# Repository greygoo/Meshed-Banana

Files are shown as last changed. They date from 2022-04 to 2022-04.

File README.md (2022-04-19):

# THIS IS WORK IN PROGRESS, PLEASE IGNORE UNTIL THIS MESSAGE IS REMOVED *

# Meshed Banana

</p>
<p align="center" width="60%">
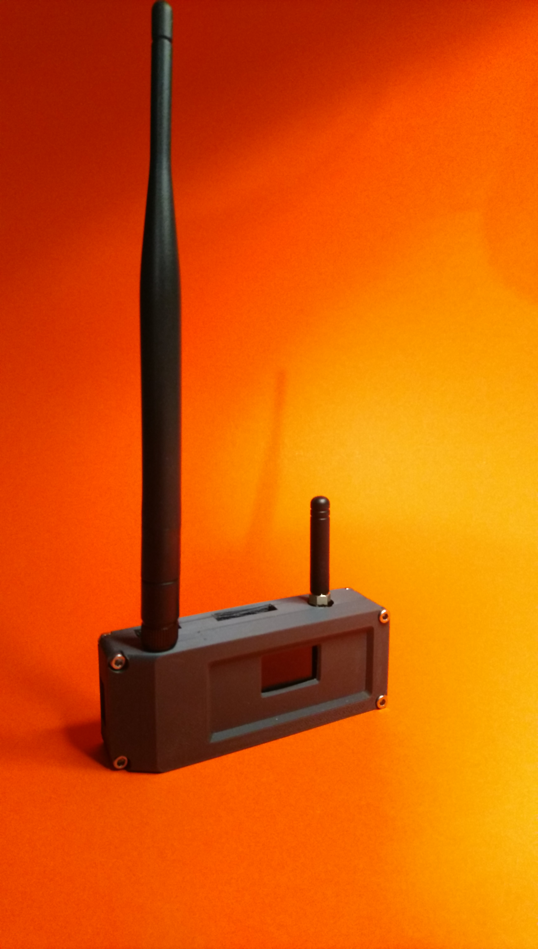
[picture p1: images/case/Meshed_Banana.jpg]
  
</p>

## What is it?
Meshed Banana is LoRa Router for the Reticulum Mesh protocol. It consists of a ESP32 LoRa device connected to a Banana Pi Zero M2 running the reticulum mesh network stack.

_Why a Banana Pi Zero?_
_Simply due to the sparsity of the Raspberry Pi Zero, the Banana Pi version was chosen as it has the same size and thus can be exchanged, giving you the option of a Meshed Raspberry. All build instructions given here can also be applied to a raspberry pi zero, only the Banana Pi Zero disk image will not work on a Raspberry Pi, a working image will be provided in the future._
 
## What can it do?
Other than mesh networking projects like e.g. meshtastic, the reticulum stack is not restricted to a LoRa network, but can also be used over other rf based networks like cb radio as well as internet protocols like TCP/IP or I2P. This enables users to bridge LoRa networks into the internet and thus giving the ability to connect separated rf based networks or extend connectivity via rf.

The "downside" of the reticulum stack is that it is not running on the microprocessor itself, but is written in python and thus requires some python capable system - here the banana pi zero (it is not yet micropython capable, the main missing part is the python cryptography module).

## What can't it do?
Reticulum, despite its stability, is still in an early stage. Therefor a number of features have not yet been implemented. Also, it is an own protocol, requiring applications to make use of it. Currently there are only a number of examples and a chat application that can be used for testing. However - creating your own applications in Python is not very difficult and an introduction can be found here: <link to reticulum own apps>. So here a short overview of what works and what does not work yet:

Works:
- Mesh network functionality over TCP/IP, I2P, KISS, LoRa
- SMS like direct 1on1 chat using a terminal application or an Android phone
- Serving and accessing pages written in a markdown like language
- Dending and receiving files
- Using the reticulum capable [Sideband Android App](https://unsigned.io/sideband/)

Does not work (yet)
- group chat
- a lot I can't think of right now ;)

For more details on reticulum features and a roadmap, please check out the [documentation on reticulum](https://markqvist.github.io/Reticulum/manual/)  
  
## How does it work?
The principle of Meshed Banana is to connect on one side to other LoRa nodes in range and on the other side to a local Wifi network. It then runs a reticulum mesh node which is accessible from Wifi and LoRa and forwards reticulum packages from one network to the other.
This gives some possible use cases:
- Run sensors in a LoRa network, and access the data via your WiFi network on e.g. a mobile phone that runs a reticulum enabled app
- Put a Meshed Banana in your home and in your neighbors home and enjoy your fully private encrypted mesh network
- Connect a cb radio via an TNC to two Meshed Bananas and connect two isolated sites over large distances
- ...

## What does it include?
Meshed Banana tries to make it as easy as possible to use reticulum, therefor it consists of:
- stl files for a case<link>
- instructions on how to connect everything<link>
- a banana pi zero m2 armbian image including all required software<link>

## Why don't you just connect a ESP32 Lora device to your Laptop?
That would be too easy ;)
The main reason for this project was to create a device that can be given to unexperienced user to enable him to take part in a LoRa Mesh network withou much for him to setup.

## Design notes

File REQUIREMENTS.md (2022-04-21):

# Required Hardware

## Banana Pi Zero

**Name** Banana Pi M2 Zero<br>
**URL** https://wiki.banana-pi.org/Banana_Pi_BPI-M2_ZERO<br>
**Source** https://www.reichelt.de/banana-pi-m2-zero-1-2-ghz-quad-core-512-mb-ddr3-banana-pi-zero-p218297.html<br>

<p align="left" width="60%">
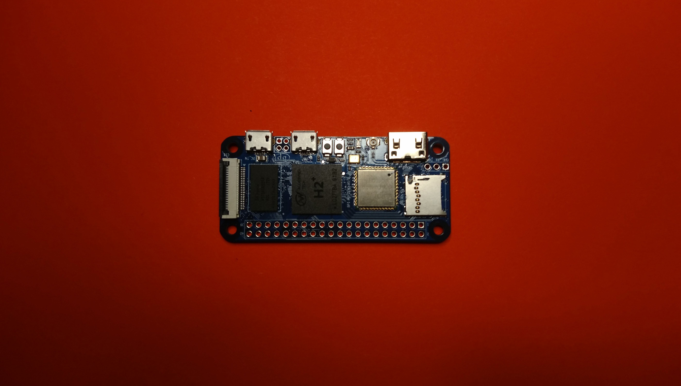
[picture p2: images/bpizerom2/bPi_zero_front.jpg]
  
</p>

## ESP32 based LoRa module

**Name** LILYGO® TTGO ESP32-Paxcounter LoRa32 V2.1 1.6<br>
**URL** http://www.lilygo.cn/prod_view.aspx?TypeId=50003&Id=1130&FId=t3:50003:3<br>
**Source** https://www.ebay.de/itm/164396959192<br>
**Frequency** 868 Mhz<br>

<p align="center" width="60%">
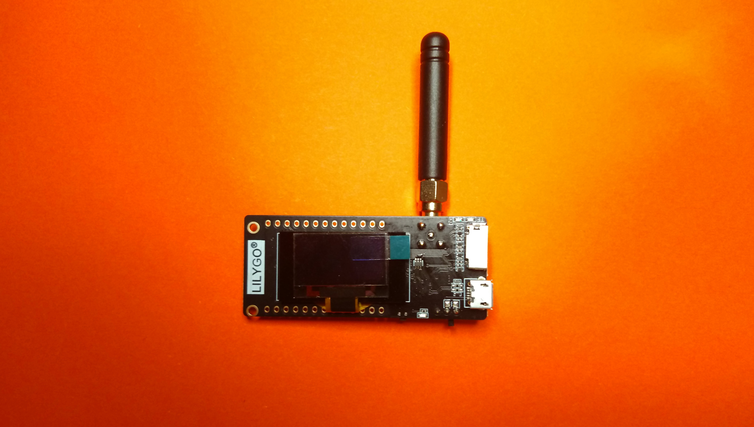
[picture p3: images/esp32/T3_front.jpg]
  
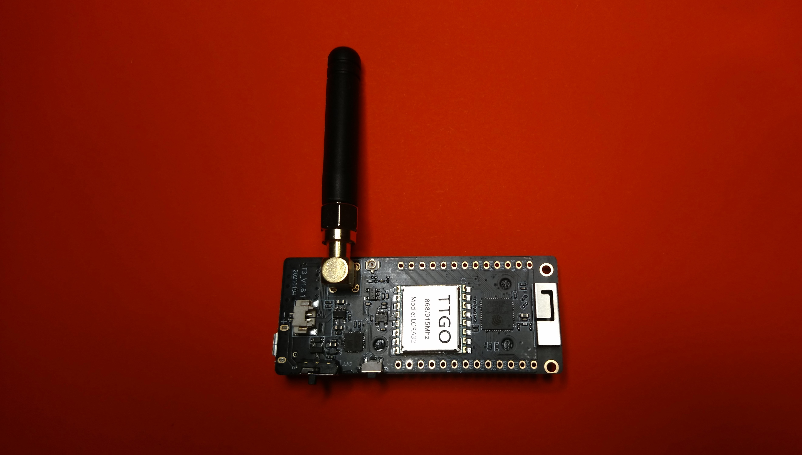
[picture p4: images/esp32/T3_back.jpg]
  
</p>

## WIFI Antenna

**Name** 2.4GHz WIFI antenna SMA Female<br>
**Source** https://www.ebay.de/itm/183989745716<br>

## SMA - IPEX adapter cable

**Name** RP-SMA(Male) to IPEX/U.FL Pigtail Cable<br>
**Source** https://www.ebay.de/itm/265495161098<br>

## Wires

Each approx. 30cm:
- red
- black
- green
- blue

## Connectors

1x Dupont connector female (6 pin)<br>
1x JST SM connector female (4 pin)<br>
1x JST SM connector male (4 pin)

## Screws

2x M2 x 5mm
4x M2.5 x 5mm
2x M3 x 18mm
2x M3 x 25mm

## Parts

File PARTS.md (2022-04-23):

# Required Hardware

## Banana Pi Zero

**Name** Banana Pi M2 Zero<br>
**URL** https://wiki.banana-pi.org/Banana_Pi_BPI-M2_ZERO<br>
**Source** https://www.reichelt.de/banana-pi-m2-zero-1-2-ghz-quad-core-512-mb-ddr3-banana-pi-zero-p218297.html<br>

<p align="left" width="60%">
  
</p>

## ESP32 based LoRa module

**Name** LILYGO® TTGO ESP32-Paxcounter LoRa32 V2.1 1.6<br>
**URL** http://www.lilygo.cn/prod_view.aspx?TypeId=50003&Id=1130&FId=t3:50003:3<br>
**Source** https://www.ebay.de/itm/164396959192<br>
**Frequency** 868 Mhz<br>

<p align="left" width="60%">
  
  
</p>

## WIFI Antenna

**Name** 2.4GHz WIFI antenna SMA Female<br>
**Source** https://www.ebay.de/itm/183989745716<br>

<p align="left" width="60%">
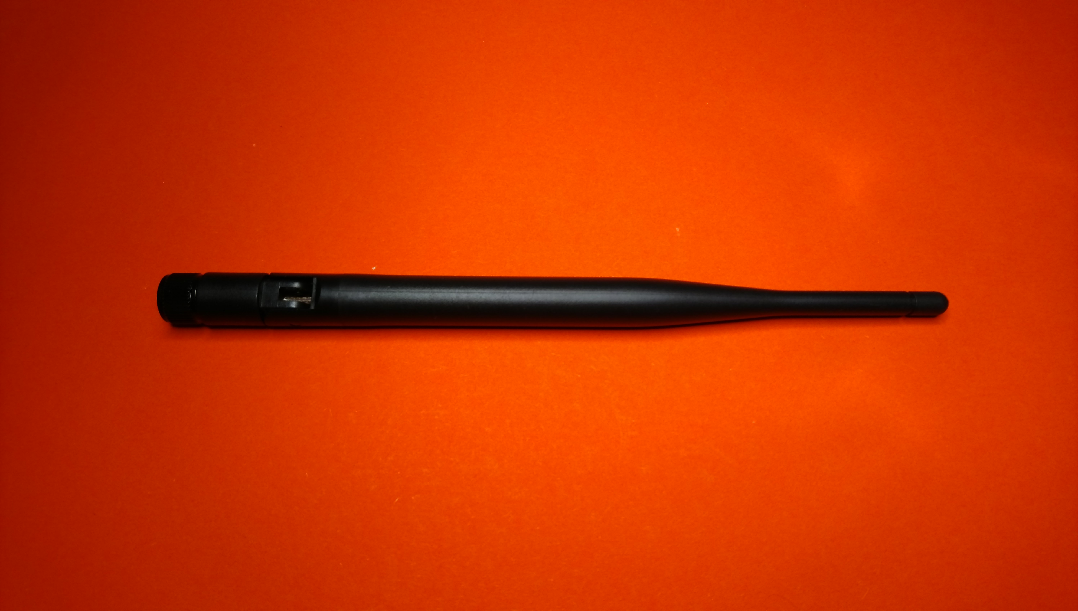
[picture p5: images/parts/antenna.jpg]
  
</p>

## SMA - IPEX adapter cable

**Name** RP-SMA(Male) to IPEX/U.FL Pigtail Cable<br>
**Source** https://www.ebay.de/itm/265495161098<br>

<p align="left" width="60%">
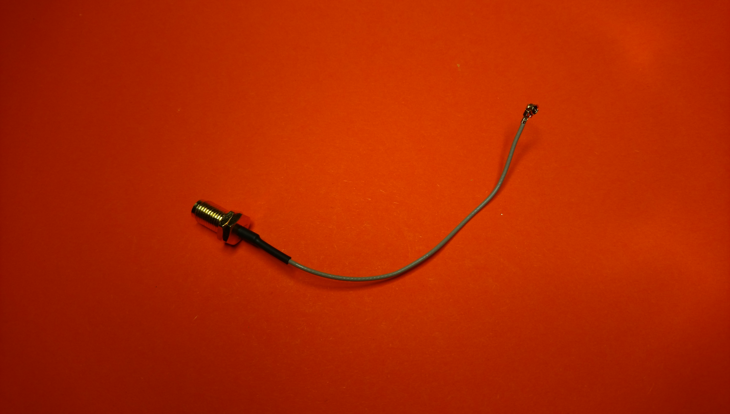
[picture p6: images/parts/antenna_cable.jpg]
  
</p>

## Connectors

1x Dupont connector female (6 pin)<br>

<p align="left" width="60%">
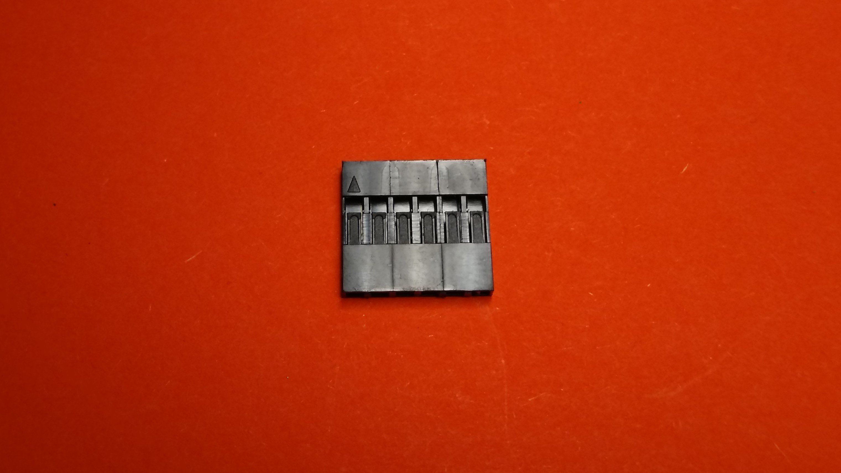
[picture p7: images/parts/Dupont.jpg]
  
</p>

1x JST SM connector female (4 pin)<br>
1x JST SM connector male (4 pin)
<p align="left" width="60%">
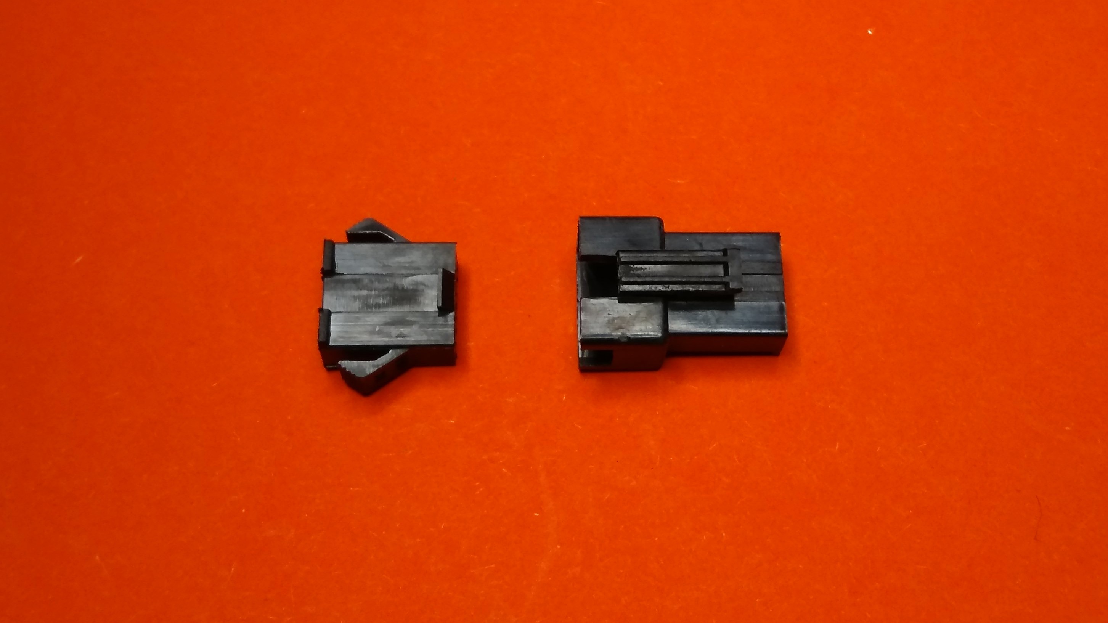
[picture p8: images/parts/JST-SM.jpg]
  
</p>

## Screws

2 x M2 x 5mm<br>
4 x M2.5 x 5mm<br>
2 x M3 x 18mm<br>
2 x M3 x 25mm

## Wires

Approx. 10cm:<br>
1 x Red<br>
1 x Black<br>
1 x Green<br>
1 x Blue<br>

Approx. 4cm:<br>
1 x Red<br>
2 x Black<br>
2 x Green<br>
2 x Blue<br>

Continue with [soldering in the wires](BUILD.md)

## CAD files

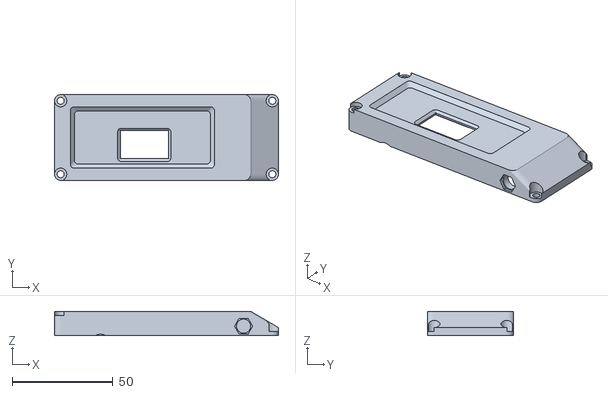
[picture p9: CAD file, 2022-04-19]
case/stl/Meshed_Banana_top.stl
111.0 x 42.5 x 12.0

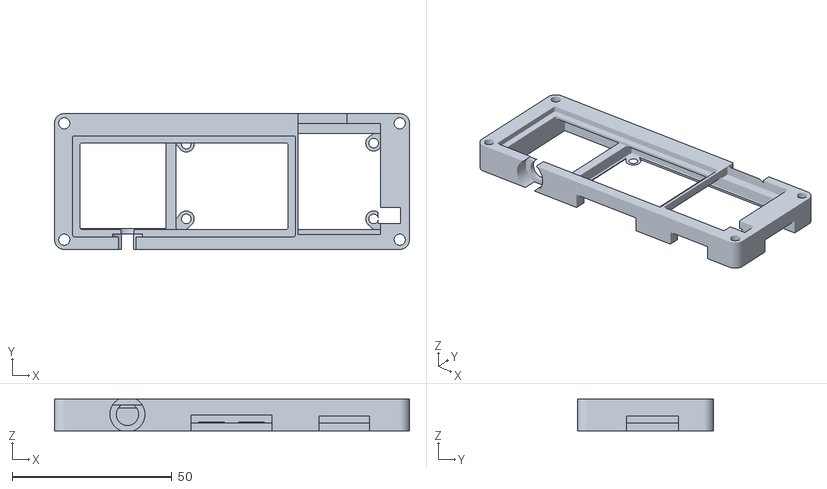
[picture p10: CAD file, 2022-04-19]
case/stl/Meshed_Banana_middle.stl
111.0 x 42.5 x 9.90

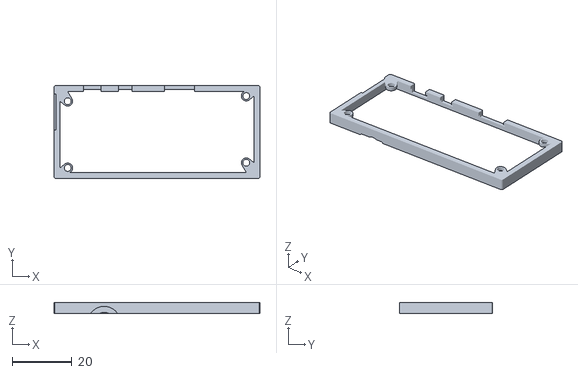
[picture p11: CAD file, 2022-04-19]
case/stl/Meshed_Banana_inlay_t3.stl
69.0 x 31.0 x 3.60

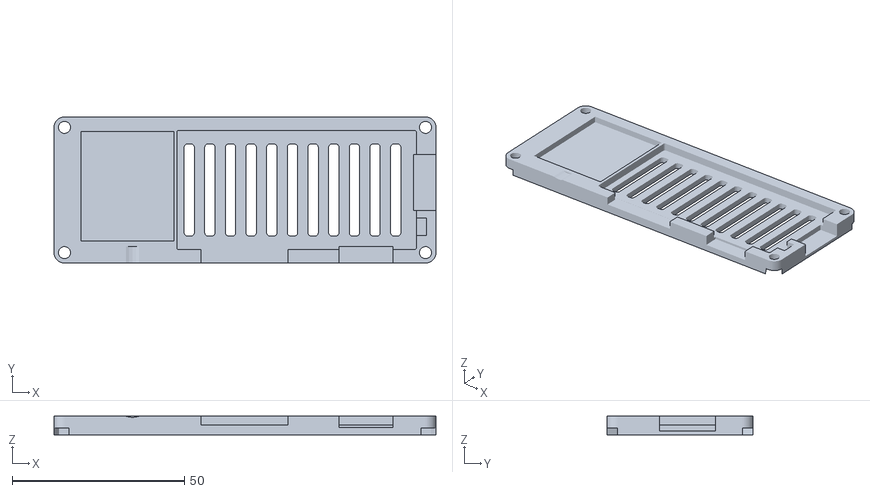
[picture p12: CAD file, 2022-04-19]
case/stl/Meshed_Banana_bottom.stl
111.0 x 42.5 x 5.40

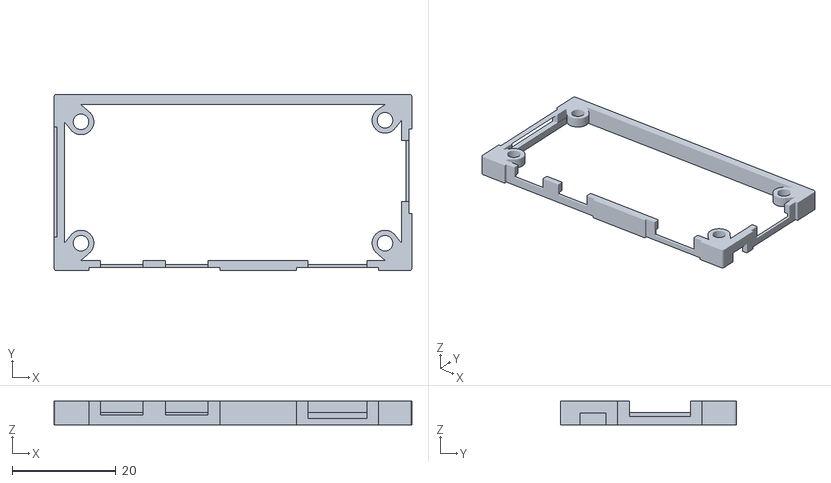
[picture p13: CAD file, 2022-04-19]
case/stl/Meshed_Banana_inlay_pi.stl
69.0 x 34.0 x 4.60

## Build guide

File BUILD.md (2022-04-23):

# Build

**Notes**

- TXD/RXD lines have to be crossed for a serial connection. This is achieved by switching the blue and green wire when soldering it into TXD and RXD connection, as seen in the pictures below.
- The TTGO LORA32 board is powered through the 3.3V pins from the Banana Pi Zero M2
- If you plan to use an HDMI monitor instead of a FTDI<->USB adapter, you can skip installing the debug connections (Steps 1 and 5)
- Your FTDI<->USB Adapter might have a different pinout, please make sure you put the pins into the Dupont connector accordingly (RXD/TXD lines crossed!).

1. Solder the 3 cables for the debug connection and 4 cables for the connection with the LORA3 to the Banana Pi Zero M2 

<p align="left" width="60%">
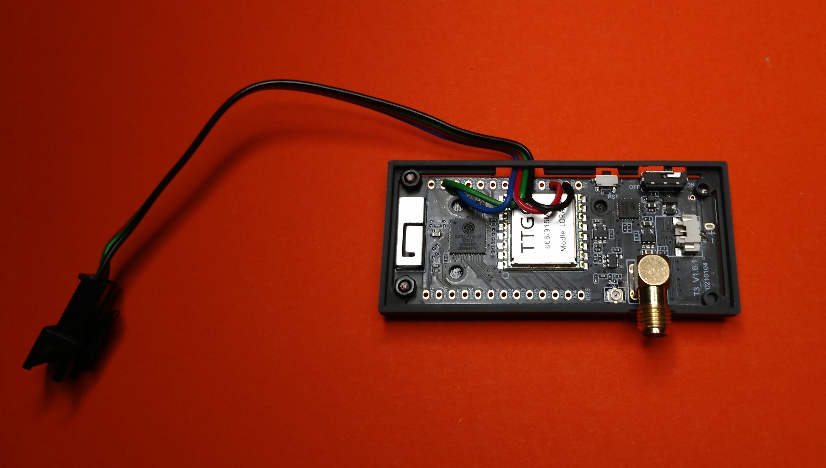
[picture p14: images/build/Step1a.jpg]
  
  
</p>

2. Solder the 4 cables for the connection with the LORA3 to the Banana Pi Zero M2 

<p align="left" width="60%">
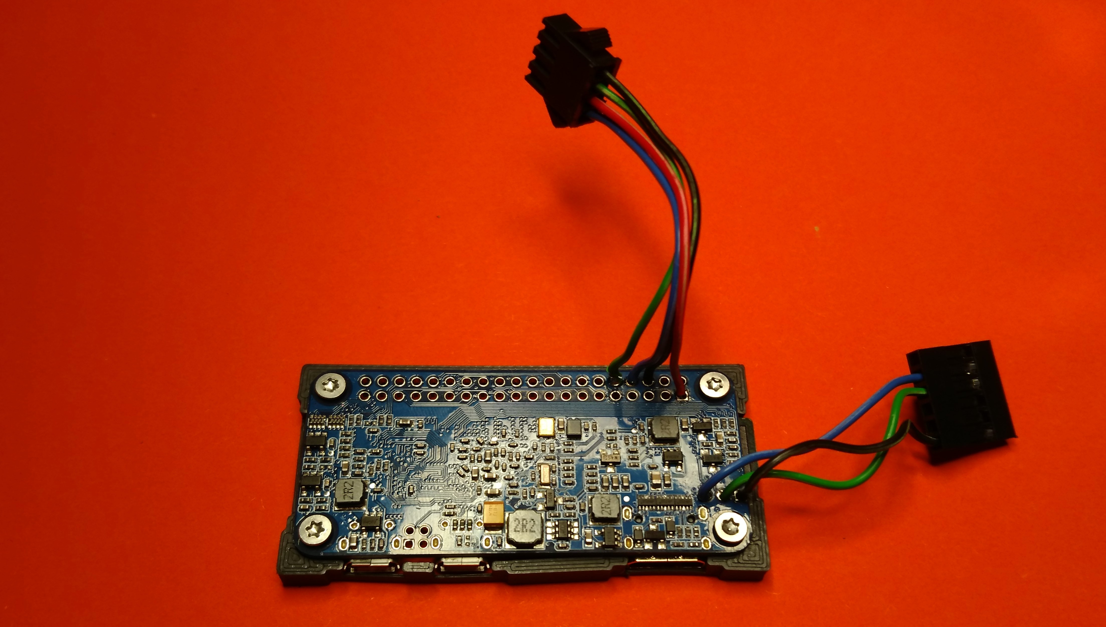
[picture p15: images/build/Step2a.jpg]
  
  
</p>

3. Solder the 4 cables for the connection with the Banana Pi Zero M2 to the TTGO LORA32

<p align="left" width="60%">
  
  
</p>

4. Join the JST-SM connectors with the 4 cables connecting Banana Pi Zero and TTGO LORA32

<p align="left" width="60%">
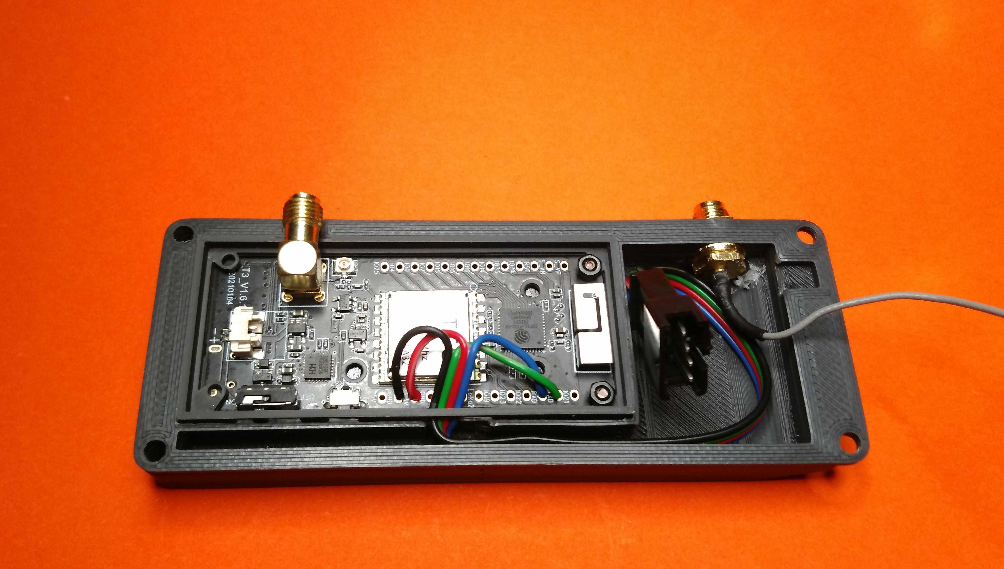
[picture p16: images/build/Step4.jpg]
  
</p>

5. Join the Dupont connector with the three debug cables from the Banana Pi Zero M2

<p align="left" width="60%">
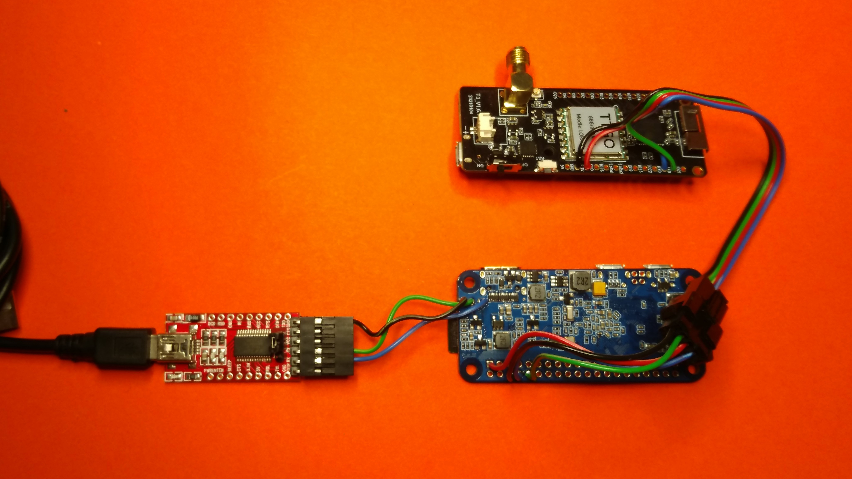
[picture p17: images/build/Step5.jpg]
  
</p>

6. Banana Pi Zero M2, TTGO LORA32 and a FTDI<->USB adapter connected

<p align="left" width="60%">
  
</p>

Continue with the [Assembly of the case](ASSEMBLY.md)

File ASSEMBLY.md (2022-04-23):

# Assembly

1. Screw the LoRa32 module in its frame using 2mm screws.
</p>
<p align="left" width="60%">
  
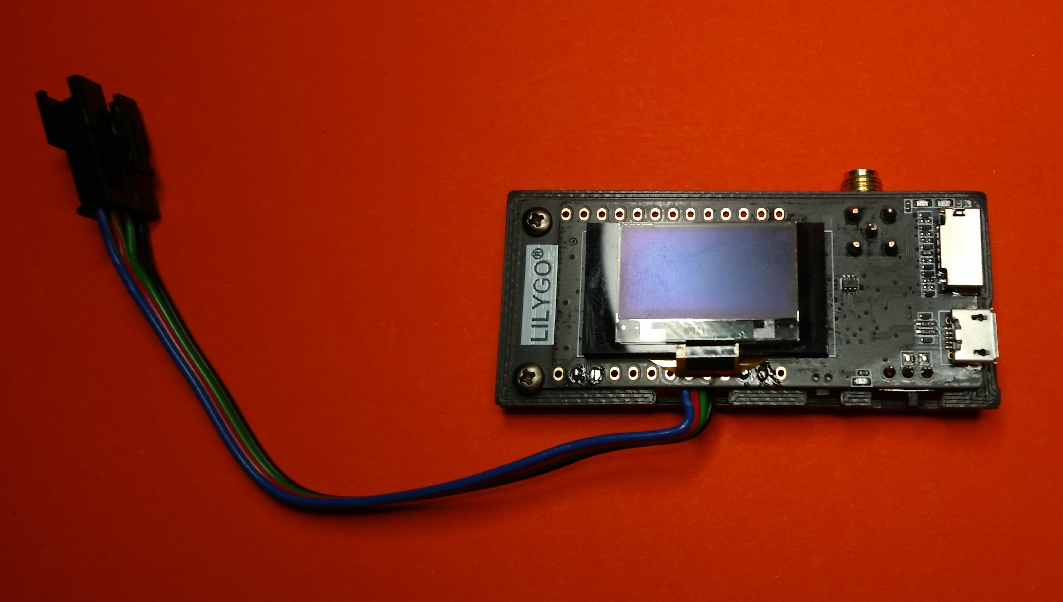
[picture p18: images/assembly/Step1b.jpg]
  
</p>

2. Screw the Banana Pi Zero into its frame using 2.5mm screws.
</p>
<p align="left" width="60%">
  
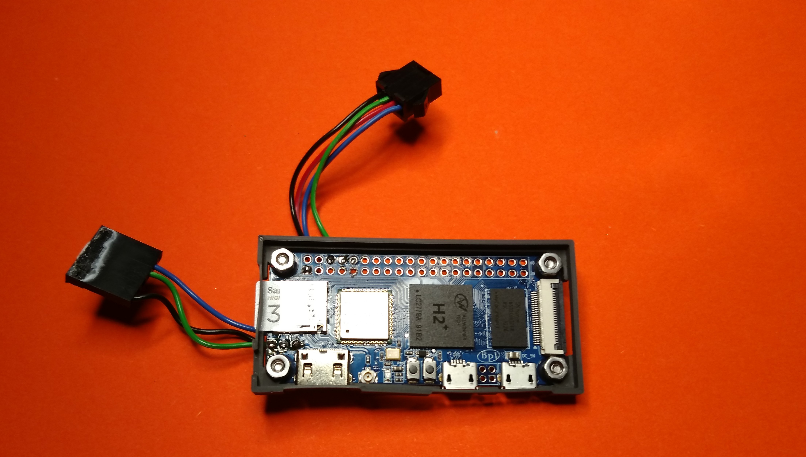
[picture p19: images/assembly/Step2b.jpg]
  
</p>

3. Screw the Antenna Cable into the top part of the case.
</p>
<p align="left" width="60%">
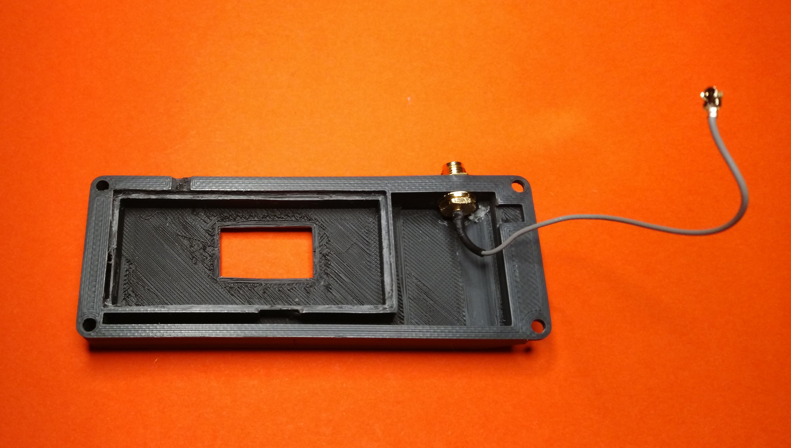
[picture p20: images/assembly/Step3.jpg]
  
</p>

4. Put the LoRa32 into the top case, make sure to run the cables as shown in the picture.
</p>
<p align="left" width="60%">
  
</p>

5. Add the middle part of the case.
</p>
<p align="left" width="60%">
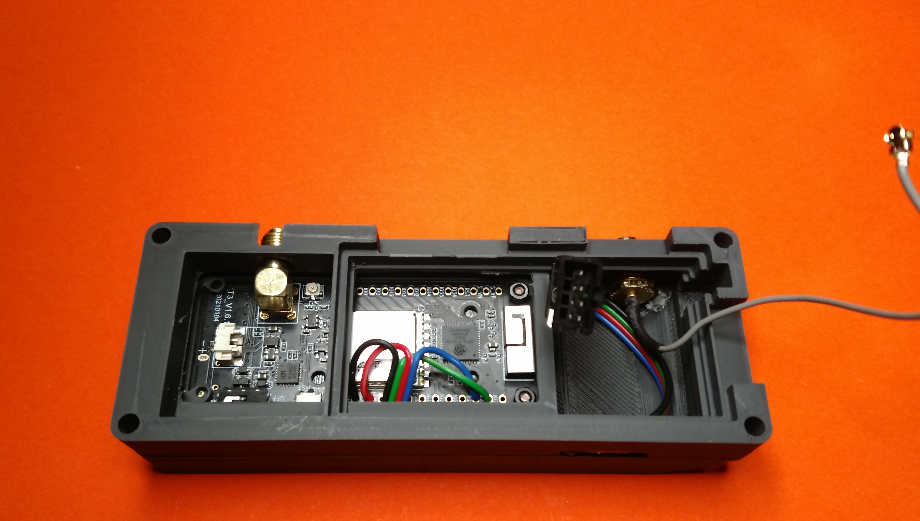
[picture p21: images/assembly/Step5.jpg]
  
</p>

6. Connect the Banana Pi Zero to the LoRa32 module and place the JST-SM connector in the case as shown in the picture.
</p>
<p align="left" width="60%">
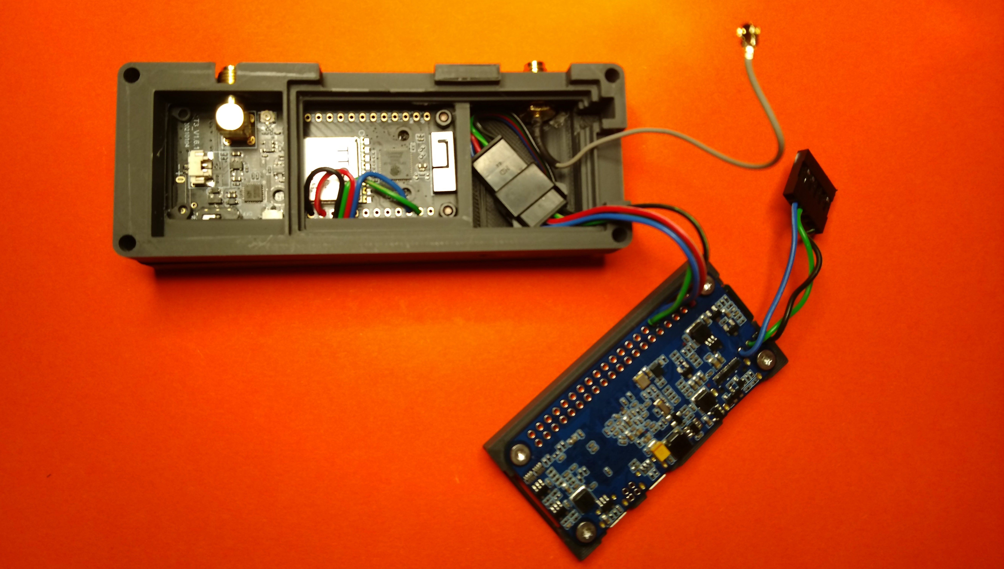
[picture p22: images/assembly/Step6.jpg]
  
</p>

7. Put the Dupont debug connector in the slot between top and middle case parts (It should be held in place once screws are tightened).
</p>
<p align="left" width="60%">
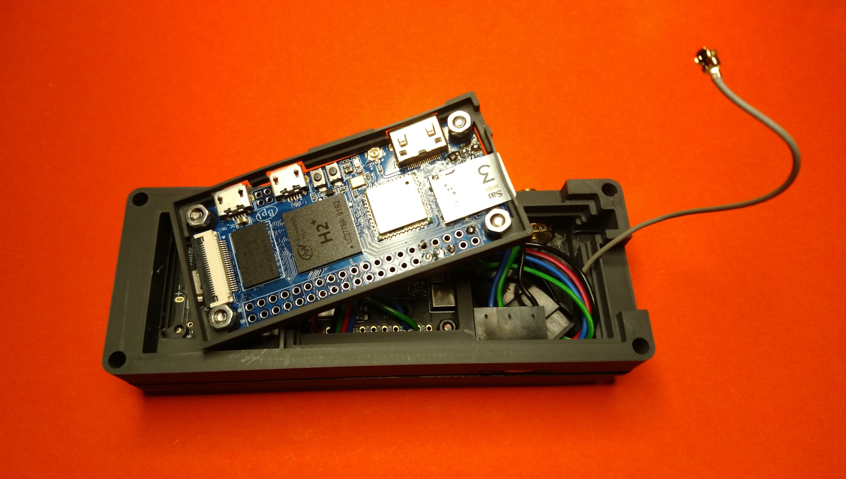
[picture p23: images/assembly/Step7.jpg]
  
</p>

8. Place the Banana Pi Zero in the middle case part. Lead the antenna cable through the gap and plug it into the Banana Pi Zero
</p>
<p align="left" width="60%">
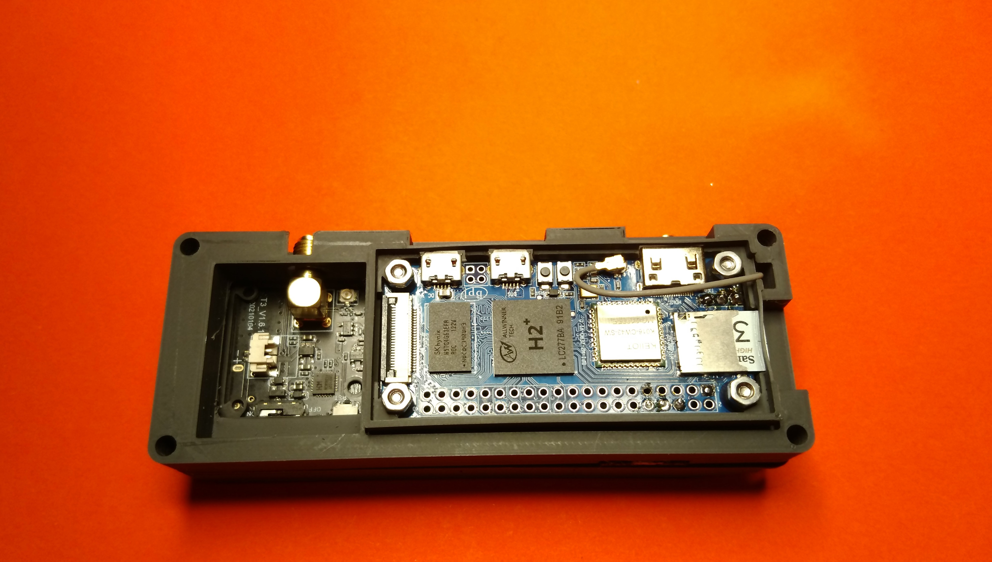
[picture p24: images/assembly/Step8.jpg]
  
</p>

9. Put the bottom case part on top and use 3mm screws to tighten it.
</p>
<p align="left" width="60%">
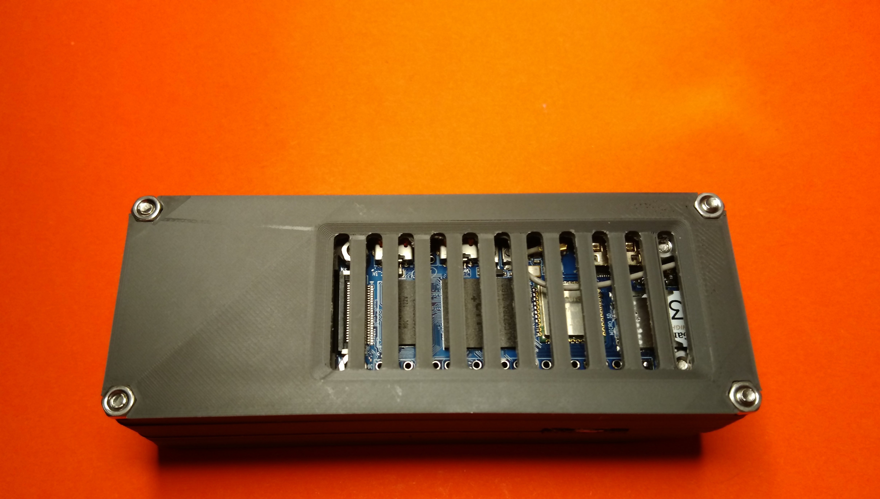
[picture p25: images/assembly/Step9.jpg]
  
</p>

10. Attach the antennas.
</p>
<p align="left" width="60%">
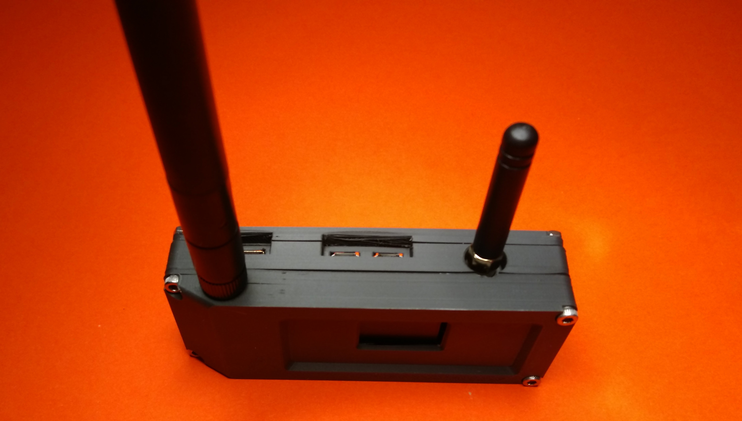
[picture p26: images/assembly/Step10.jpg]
  
</p>

11. One of:
  - Attach an serial<->USB adapter to the debug port and connect it via USB with your PC.
  - Connect a monitor via the HDMI port.
</p>
<p align="left" width="60%">
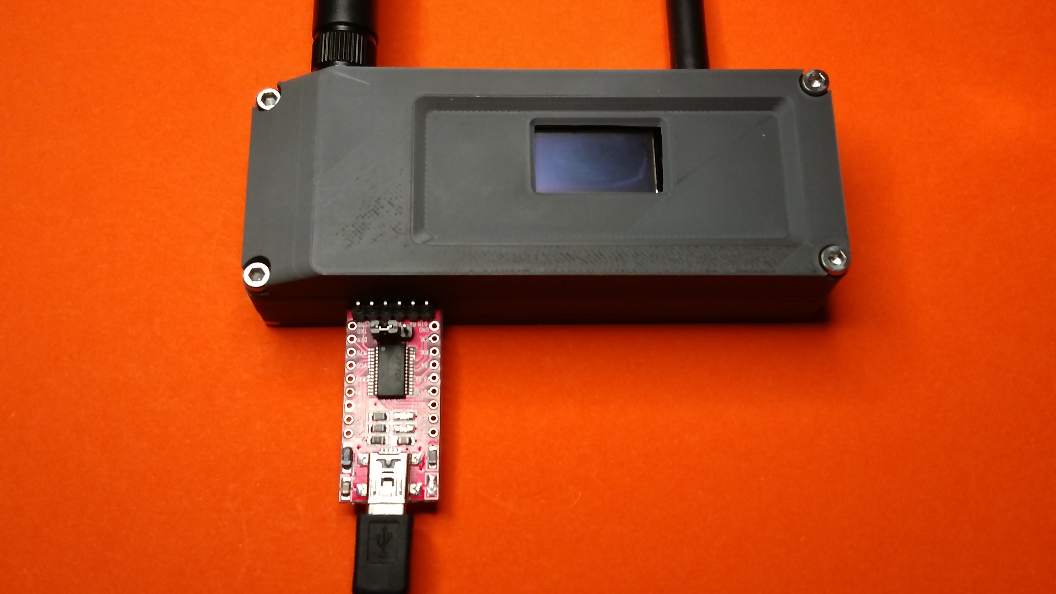
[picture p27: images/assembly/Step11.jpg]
  
</p>

Continue with [Setting up the System](SETUP.md)

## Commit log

2022-04-19 Add stl files
    [Meshed_Banana_bottom.stl, Meshed_Banana_inlay_pi.stl, Meshed_Banana_inlay_t3.stl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]
2022-04-21 Add ASSEMBLY documentation, fix image numbering, add documentation placeholders
2022-04-21 Add description on how to connect antenna cable
2022-04-23 Update the wire list and add links to next sections
